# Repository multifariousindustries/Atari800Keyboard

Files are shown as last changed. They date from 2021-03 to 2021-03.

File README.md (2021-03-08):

# Atari 800 Keyboard

Despite using a variety of keyboard manufacturers and designs over its production, it seems that all Atari 800 computers have a keyboard that is destined to fail, if it hasn't already. Luckily, we live in a time where making completely custom keyboards is a hobby, so I figured I could take advantage of this to create a brand new, drop-in replacement keyboard using commonly available parts. 

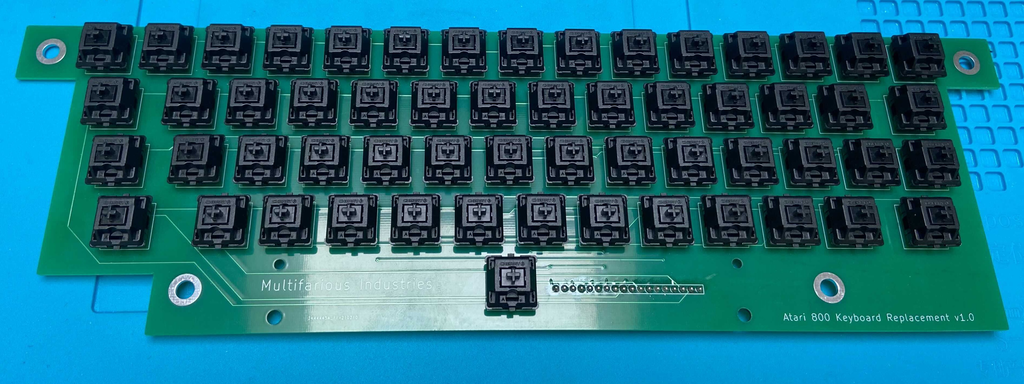
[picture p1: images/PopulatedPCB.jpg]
Assembled PCB


## Goals

- Drop-in replacement with no modding of the Atari necessary
- Use widely available Cherry MX style switches, so others can choose the feel they prefer.
- Reuse original key caps to keep the original look

# Making your own

## Parts Needed
- 1 PCB 
- 57 Cherry MX style PCB mount switches
- 18 pin right angle header
- 18 Female-Female jumper wires
- 3d printed parts (see Keys and Mounting below)

## PCB

The KiCad files are in the [PCB](/PCB) folder. Also included is a [.zip](/PCB/Atari800Keyboard.zip) file you can upload to your favorite board house for manufacturing. It's a 2 layer design with some vias connecting the sides, so making the PCB at home might be a challenge. 

Assembly is straight forward. Each switch location is labeled for what key it is. Insert PCB mount switches, solder the pins and solder on righit angle pin headers on the bottom for the connection to the Atari. 

I was unable to find 18 pin ribbon cables with single row connectors, so I opted to use a strip of female to female jumper wires. You could also use half of the connections of an IDE cable. 

## Adding Keys

I wanted to use the original key caps from the Atari, as they have special legends and sizes that would be hard to recreate in a modern cap. This required designing a 3D printable adapter to connect the Hi-tek/Stackpole caps to a Cherry MX stem. This adds significant height to the keys, but luckily the original PCB (and therefore the replacement) sit very low in the case and the height of the adapters allow the keys to sit at the same height as the OEM keyboard. The adapters are simply pressed onto the Cherry MX stems and then the Atari caps are pressed into the other side. Friction keeps everything in place. 

### Stackpole Caps

The PCB was designed with the same switch locations as the Stackpole keyboard, so you just need to print 57 of the [standard adapters](/STL/StackpoleMXAdapterV3.1.stl). These are very small and you should be able to print them all at once on most printers. They should be printed with the MX + side facing up and supports are not needed. 

### Hi-Tek Caps

The Hi-tek board I have used caps with offset posts for the larger keys such as the shift and enter keys. Since I only had a stackpole keyboard when designing the PCB, I created special adapter for the 1.5 unit and 2 unit wide keycaps. You'll need to print four of the [1.5u adapters](/STL/StackpoleMXAdapter-1.5U.stl), one [2u adapter](/STL/StackpoleMXAdapter-2U.stl), and 52 of the [standard adapters](/STL/StackpoleMXAdapterV3.1.stl). Both the wide and standard adapters should be printed with the MX + side facing up and supports are not needed. 

## Mounting the Keyboard

Print two of the [bottom mounts](/STL/BottomMount.stl), and one of each of the top [left](/STL/TopLeftMount.stl), [center](/STL/TopCenterSupport.stl), and [right](/STL/TopRightMount.stl) mounts. The two bottom mounts slide over the bottom edge of the PCB and line up with the mounting holes to ensure the PCB sits at the correct hight, relative to the case. The three top mount pieces are also used for aligning the board, but also serve to support the top of the board and keep it from flexing during use.

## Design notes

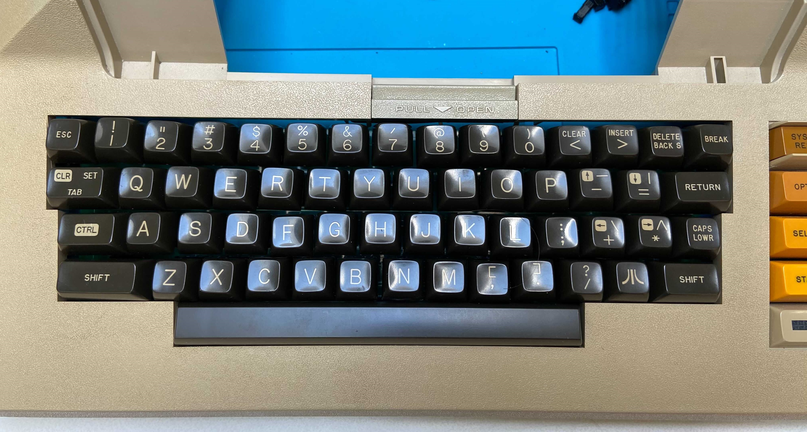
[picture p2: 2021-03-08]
images/FinishedProduct.jpg

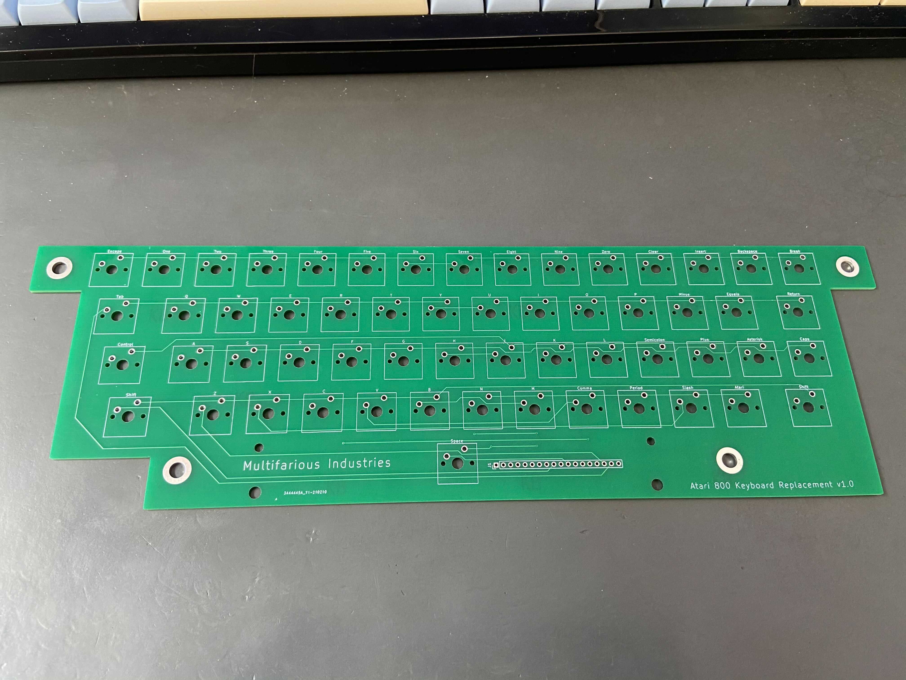
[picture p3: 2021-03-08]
images/BarePCB.jpg

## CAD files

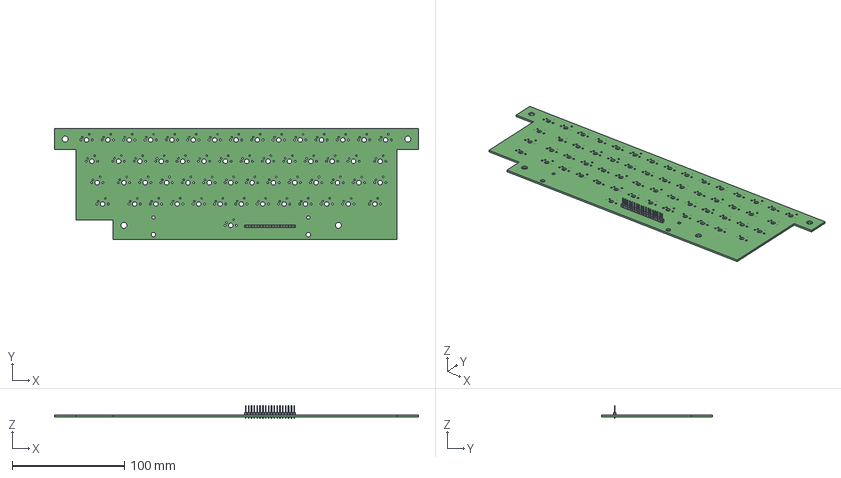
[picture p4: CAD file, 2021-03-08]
PCB/Atari800Keyboard.step
324.6 x 99.2 x 11.5 mm

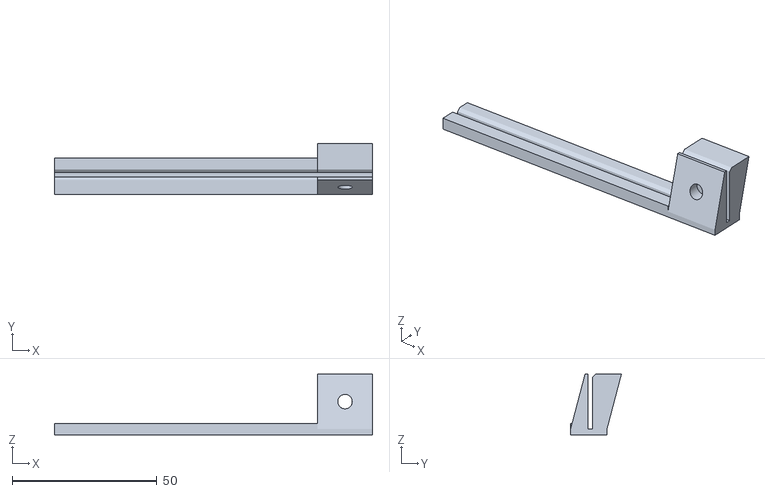
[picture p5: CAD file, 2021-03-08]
STL/TopRightMount.stl
110.0 x 17.6 x 21.0

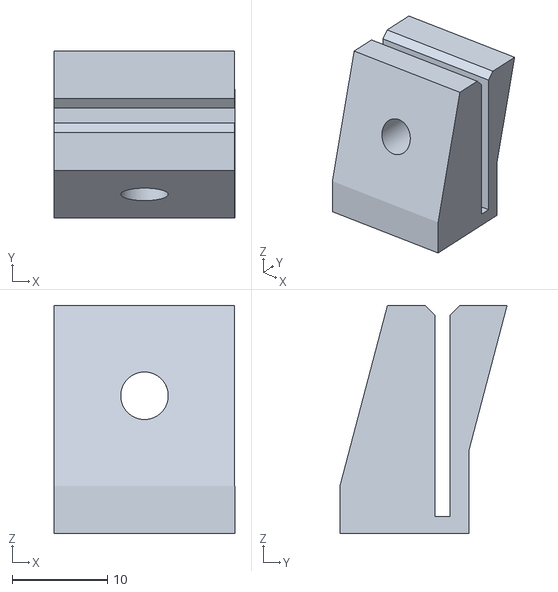
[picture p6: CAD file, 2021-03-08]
STL/BottomMount.stl
19.0 x 17.6 x 24.0

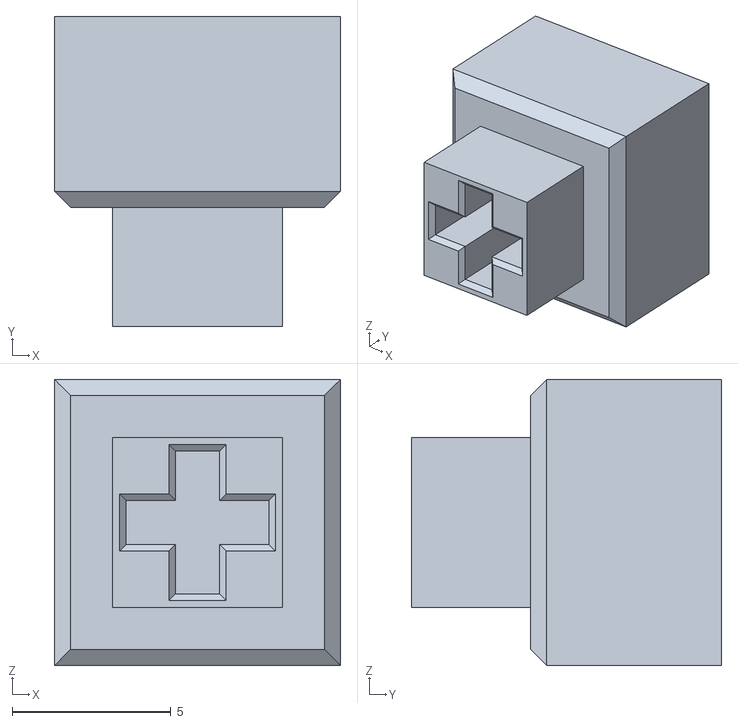
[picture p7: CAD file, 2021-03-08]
STL/StackpoleMXAdapterV3.1.stl
9.00 x 9.75 x 9.00

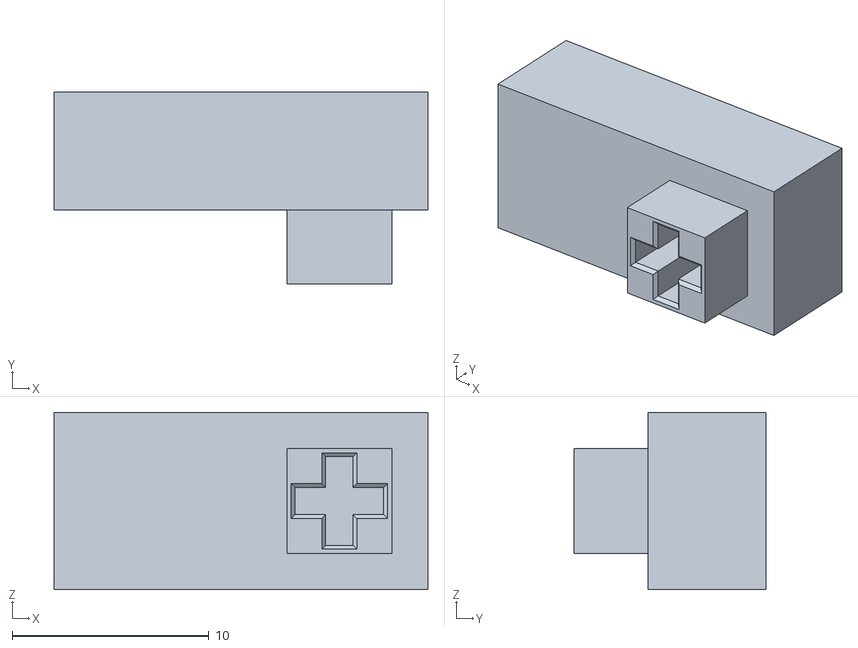
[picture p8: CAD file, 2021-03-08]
STL/StackpoleMXAdapter-2U.stl
19.0 x 9.75 x 9.00

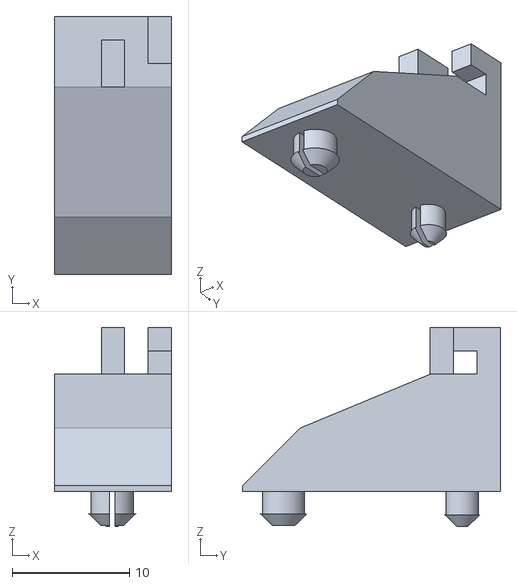
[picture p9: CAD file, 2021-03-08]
STL/SpaceBarSupportV1.1.stl
10.0 x 22.0 x 17.0

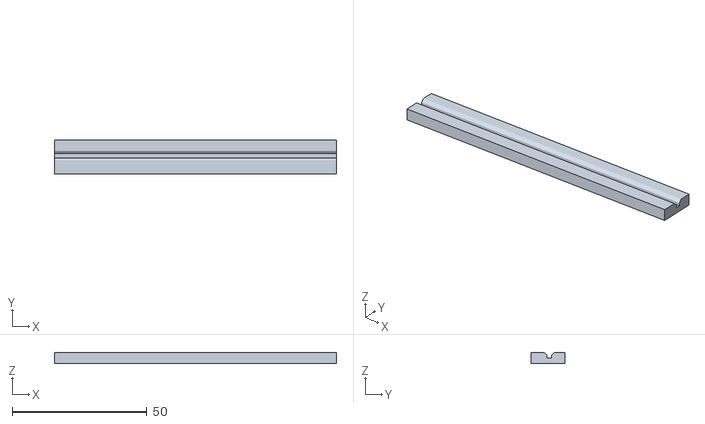
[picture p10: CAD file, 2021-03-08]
STL/TopCenterSupport.stl
104.6 x 12.6 x 4.00

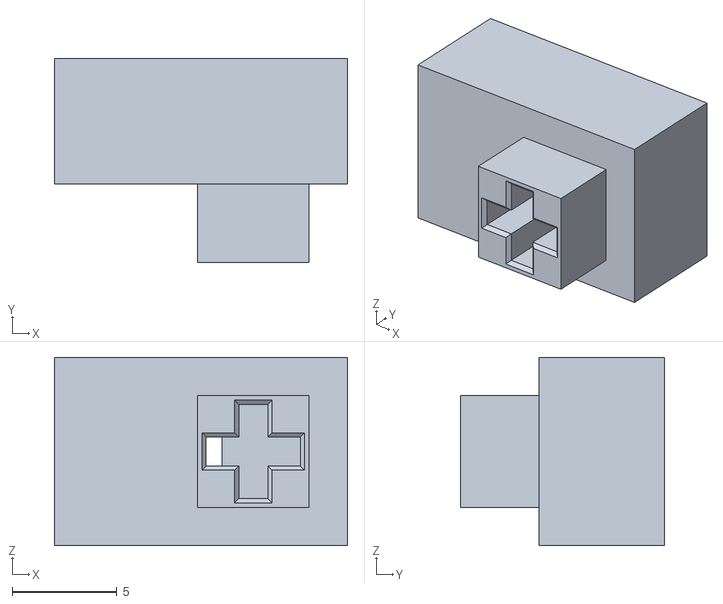
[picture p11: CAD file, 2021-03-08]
STL/StackpoleMXAdapter-1.5U.stl
14.0 x 9.75 x 9.00

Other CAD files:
STL/TopLeftMount.stl

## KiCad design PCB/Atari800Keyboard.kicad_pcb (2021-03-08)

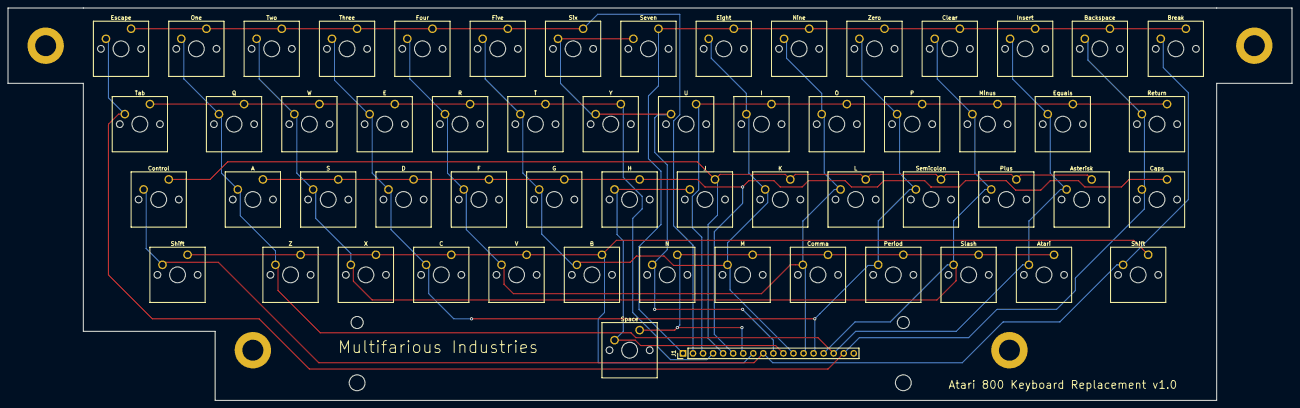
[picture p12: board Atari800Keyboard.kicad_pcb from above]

Board: 2 copper layers, 324.6 x 99.2 mm, 58 parts (0 on the bottom side), 17 nets.

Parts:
A: KEYSW; SW_Cherry_MX_1.00u_PCB
Asterisk: KEYSW; SW_Cherry_MX_1.00u_PCB
Atari: KEYSW; SW_Cherry_MX_1.00u_PCB
B: KEYSW; SW_Cherry_MX_1.00u_PCB
Backspace: KEYSW; SW_Cherry_MX_1.00u_PCB
Break: KEYSW; SW_Cherry_MX_1.00u_PCB
C: KEYSW; SW_Cherry_MX_1.00u_PCB
Caps: KEYSW; SW_Cherry_MX_1.00u_PCB
Clear: KEYSW; SW_Cherry_MX_1.00u_PCB
Comma: KEYSW; SW_Cherry_MX_1.00u_PCB
Control: KEYSW; SW_Cherry_MX_1.50u_PCB
D: KEYSW; SW_Cherry_MX_1.00u_PCB
E: KEYSW; SW_Cherry_MX_1.00u_PCB
Eight: KEYSW; SW_Cherry_MX_1.00u_PCB
Equals: KEYSW; SW_Cherry_MX_1.00u_PCB
Escape: KEYSW; SW_Cherry_MX_1.00u_PCB
F: KEYSW; SW_Cherry_MX_1.00u_PCB
Five: KEYSW; SW_Cherry_MX_1.00u_PCB
Four: KEYSW; SW_Cherry_MX_1.00u_PCB
G: KEYSW; SW_Cherry_MX_1.00u_PCB
H: KEYSW; SW_Cherry_MX_1.00u_PCB
I: KEYSW; SW_Cherry_MX_1.00u_PCB
Insert: KEYSW; SW_Cherry_MX_1.00u_PCB
J: KEYSW; SW_Cherry_MX_1.00u_PCB
J1: Conn_01x18_Male; PinHeader_1x18_P2.54mm_Vertical
K: KEYSW; SW_Cherry_MX_1.00u_PCB
L: KEYSW; SW_Cherry_MX_1.00u_PCB
M: KEYSW; SW_Cherry_MX_1.00u_PCB
Minus: KEYSW; SW_Cherry_MX_1.00u_PCB
N: KEYSW; SW_Cherry_MX_1.00u_PCB
Nine: KEYSW; SW_Cherry_MX_1.00u_PCB
O: KEYSW; SW_Cherry_MX_1.00u_PCB
One: KEYSW; SW_Cherry_MX_1.00u_PCB
P: KEYSW; SW_Cherry_MX_1.00u_PCB
Period: KEYSW; SW_Cherry_MX_1.00u_PCB
Plus: KEYSW; SW_Cherry_MX_1.00u_PCB
Q: KEYSW; SW_Cherry_MX_1.00u_PCB
R: KEYSW; SW_Cherry_MX_1.00u_PCB
Return: KEYSW; SW_Cherry_MX_1.50u_PCB
S: KEYSW; SW_Cherry_MX_1.00u_PCB
Semicolon: KEYSW; SW_Cherry_MX_1.00u_PCB
Seven: KEYSW; SW_Cherry_MX_1.00u_PCB
Shift: KEYSW; SW_Cherry_MX_2.00u_PCB
Shift#2: KEYSW; SW_Cherry_MX_1.50u_PCB
Six: KEYSW; SW_Cherry_MX_1.00u_PCB
Slash: KEYSW; SW_Cherry_MX_1.00u_PCB
Space: KEYSW; SW_Cherry_MX_6.25u_PCB
T: KEYSW; SW_Cherry_MX_1.00u_PCB
Tab: KEYSW; SW_Cherry_MX_1.50u_PCB
Three: KEYSW; SW_Cherry_MX_1.00u_PCB
Two: KEYSW; SW_Cherry_MX_1.00u_PCB
U: KEYSW; SW_Cherry_MX_1.00u_PCB
V: KEYSW; SW_Cherry_MX_1.00u_PCB
W: KEYSW; SW_Cherry_MX_1.00u_PCB
X: KEYSW; SW_Cherry_MX_1.00u_PCB
Y: KEYSW; SW_Cherry_MX_1.00u_PCB
Z: KEYSW; SW_Cherry_MX_1.00u_PCB
Zero: KEYSW; SW_Cherry_MX_1.00u_PCB

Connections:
/Pin1: Backspace.1, Break.1, Clear.1, Eight.1, Insert.1, J1.1, Nine.1, Seven.1, Zero.1
/Pin2: Escape.1, Five.1, Four.1, J1.2, One.1, Six.1, Three.1, Two.1
/Pin3: Equals.1, I.1, J1.3, Minus.1, O.1, P.1, Return.1, U.1
/Pin4: E.1, J1.4, Q.1, R.1, T.1, Tab.1, W.1, Y.1
/Pin5: Asterisk.1, Control.1, J.1, J1.5, K.1, L.1, Plus.1, Semicolon.1
/Pin6: A.1, Caps.1, D.1, F.1, G.1, H.1, J1.6, S.1
/Pin7: Atari.1, Comma.1, J1.7, M.1, N.1, Period.1, Slash.1, Space.1
/Pin8: B.1, C.1, J1.8, Shift.1, Shift#2.1, V.1, X.1, Z.1
/Pin9: Break.2, Control.2, J1.9, Shift.2, Shift#2.2
/Pin10: J1.10, N.2, Seven.2, Six.2, U.2, Y.2
/Pin11: H.2, J.2, J1.11, Space.2
/Pin12: B.2, Eight.2, Five.2, G.2, I.2, J1.12, K.2, M.2, T.2
/Pin13: Comma.2, F.2, Four.2, J1.13, L.2, Nine.2, O.2, R.2, V.2
/Pin14: C.2, D.2, E.2, J1.14, P.2, Period.2, Semicolon.2, Three.2, Zero.2
/Pin15: Clear.2, J1.15, Minus.2, Plus.2, S.2, Slash.2, Two.2, W.2, X.2
/Pin16: A.2, Asterisk.2, Atari.2, Equals.2, Insert.2, J1.16, One.2, Q.2, Z.2
/Pin17: Backspace.2, Caps.2, Escape.2, J1.17, Return.2, Tab.2
